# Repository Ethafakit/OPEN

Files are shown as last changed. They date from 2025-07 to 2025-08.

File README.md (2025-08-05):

# Ethafa Steammians Kit
Source files and activities of the Ethafa Steammians Kit released in open source.
**Ethafa Steammians** is an open-source educational toolkit designed to introduce children (ages 9–12) to STEAM and computational thinking through culturally grounded storytelling and hands-on experimentation.

This repository provides the complete resources needed to replicate, adapt, and expand the kit in educational settings.

---

## 🌍 About the Project

The kit was developed by [Ethafa](https://www.ethafa.com) to support playful and meaningful engagement with electronics, coding, and storytelling — particularly within Arabic-speaking and multicultural communities. It has been used in workshops across Switzerland, Gulf Countries and internationally.

---

## 📦 Repository Structure
- 3D_Case
- Activities
-    ├──Code_Wiring
-    ├──ENG
-    ├──ITA
- Eolim
-    ├──GRBL
-    ├──Graphics
-    ├──Schematics
- V-NO-PCB
-    ├──Eolim_Code_Cover_3D
-    ├──Resources for Educators

---

## 🛠 How to Use

1. **Build the kit**  
   Use the 3D files and PCB source files to manufacture the hardware. Moreover, you can use the "Version with no PCB" to run the activities with simple electronics components.

2. **Run the activities**  
   Open the `Activity` folder for guided activities using the Ethafa board.  
   For NoPCB version refer to the folder "Resources for Educators"

3. **Customize**  
   Educators and designers can use the Ethafa Framework to develop new culturally grounded activities. Please share your creation using the same licence.
   We’re always happy to support and learn about new initiatives inspired by Ethafa. Feel free to share them with us at info@ethafa.com.

---

## 🧩 Contributions

We welcome educators, designers, and developers to extend the kit. We’re always happy to support and learn about new initiatives inspired by Ethafa. Feel free to reach out and share them with us at info@ethafa.com.

---

## 📄 License

All content is openly licensed:
- Educational content: CC-BY 4.0
- Hardware and PCB: CERN-OHL-S v2
- Code: MIT License

---

## 🙌 Acknowledgements
This project was developed with support from:
- Gebert Rüf Stiftung: https://www.grstiftung.ch/de.html
- Venture Kick: https://www.venturekick.ch/
- Fablab SUPSI: https://www.supsi.ch/en/fablab
- Fondazione Leonardo: https://stiftungen.stiftungschweiz.ch/organisation/fondazione-leonardo
- VCUarts Qatar: https://qatar.vcu.edu/

Collaborations
- San3a Tech: https://www.san3atech.com/
- Fablab Bahrain: https://fablab.bh/
- Makerspace AlZaina: https://make.works/companies/make_uae
- Studio 5: https://www.studio5.qa/en/
- Swissnex: https://swissnex.org/
- Fondazione Agire: https://agire.ch/
- Ated4Kids: https://ated.ch/ated4kids
- CoderDojo: https://ated.ch/coderdojo
- Arduino: https://www.arduino.cc
- Roteco: https://www.roteco.ch/

List of talks, and community engament activities: https://trite-boot-688.notion.site/List-of-talks-interviews-and-workshops-2d0f7709cc704327aacfa6989071fbab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

---

## 📚 Citation

If you use this kit or adapt it for your own project, please cite us:

```bibtex
@misc{ethafa_steammians_2025,
  title={Ethafa Steammians Kit},
  author={Tawfik, Leyla and Cangiano, Serena},
  year={2025},
  doi={10.5281/zenodo.XXXXXXX},
  url={https://github.com/ethafa/steammians-kit}
}

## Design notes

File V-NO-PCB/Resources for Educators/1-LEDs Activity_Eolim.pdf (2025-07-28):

# Help Eulim inventing great things to help the Steammians

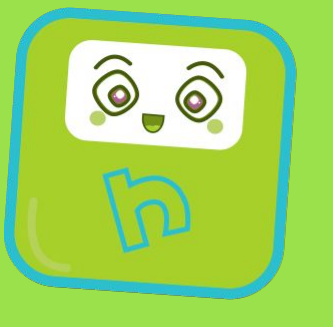
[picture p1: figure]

# live on planet earth!

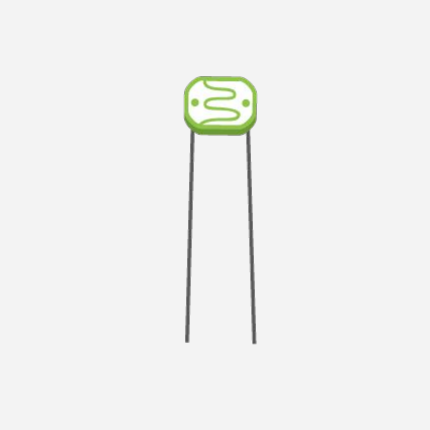
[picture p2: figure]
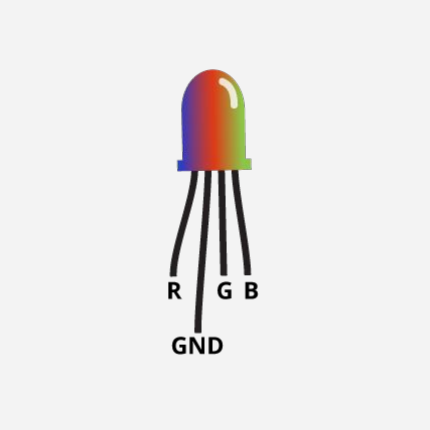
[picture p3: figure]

1x Photoresistor | 2x RGB LEDs

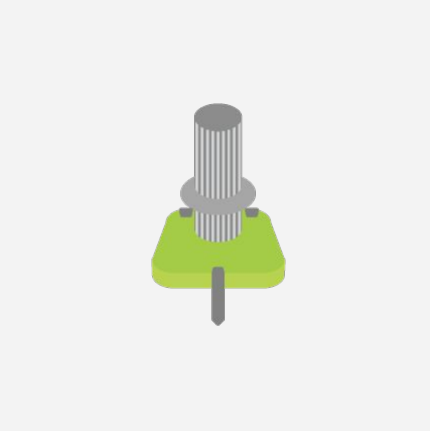
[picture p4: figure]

## 1x Potentiometer

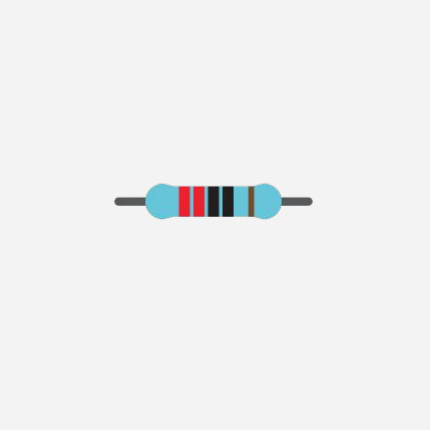
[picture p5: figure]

## 6x Resistor 220 ohm

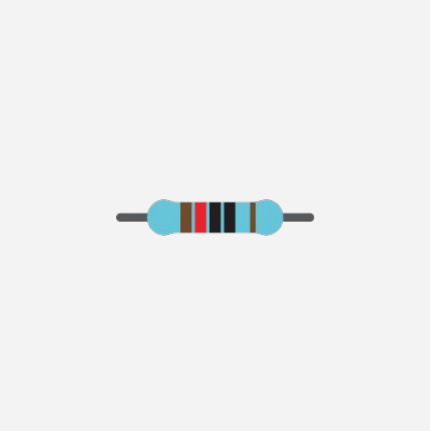
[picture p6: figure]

## 1x Resistor 10K ohm

# Here is all you need to build Eulim!

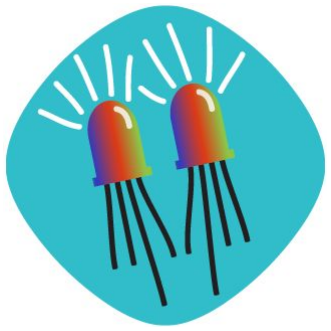
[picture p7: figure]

# Level 1 Special view

# STEP 1/4

Place the LEDs on the breadboard.

## NOTE: Remember where you place the longer lead!

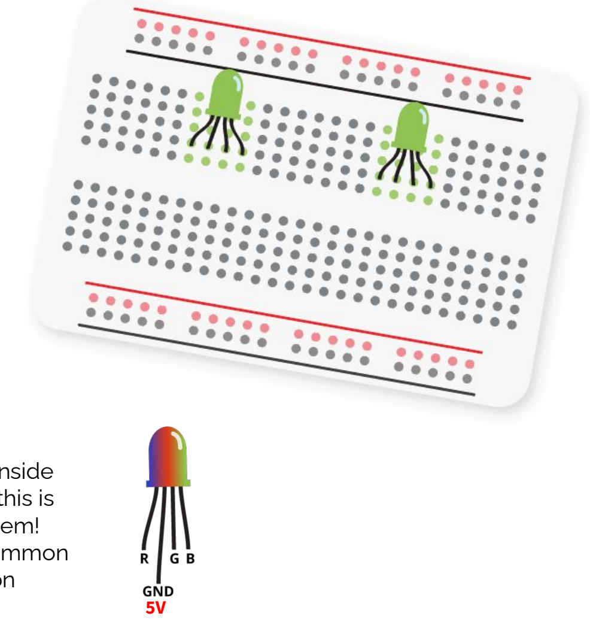
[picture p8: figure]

Electricity flows from the positive pole to the negative pole. Inside an RGB LED there 3 LEDs: one red, one green and une blue; this is why RGB LEDs can produce 3 different colors and a mix of them!
The RGB led has a longer lead than the other leads. In the common cathode case, it will be connected to GND and in the common
anode case; it will be connected to 5V. | 5V

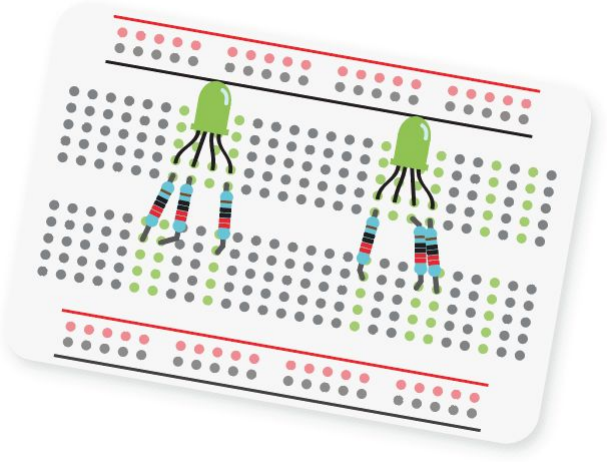
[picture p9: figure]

# STEP 2/4

## Now put the 220 ohm in correspondence of the shorter

leads.

Resistors allow changing the intensity of the electricity inside a circuit. If you don’t use them the eyes will explode!!! The intensity of electricity is measured in Ohm and you can recognize the different intensities by looking at the colored stripes.

LEARN MORE: HOW TO RESIST ELECTRICITY?

# STEP 3/4

## Connect the longer lead to the ground line on the breadboard

using two jumpers.

Jumper wires are used for making connections between items on your breadboard and your Arduino’s header pins. Use them to wire up all your circuits!

LEARN MORE: HOW TO MAKE CONNECTIONS?

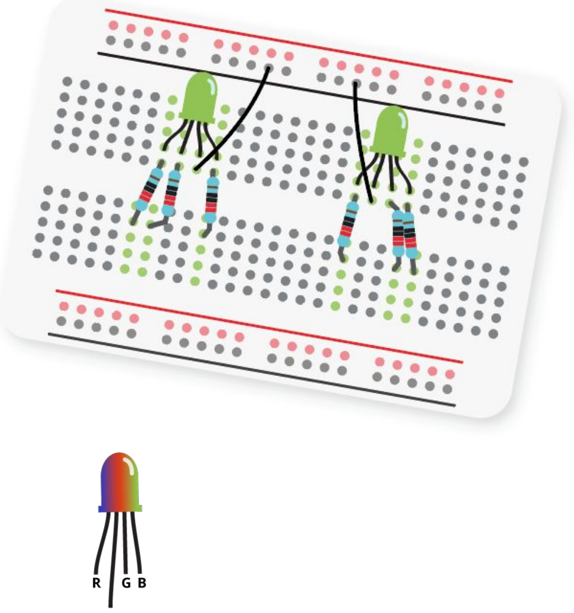
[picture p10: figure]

Remember what you read about the anode and cathode!!

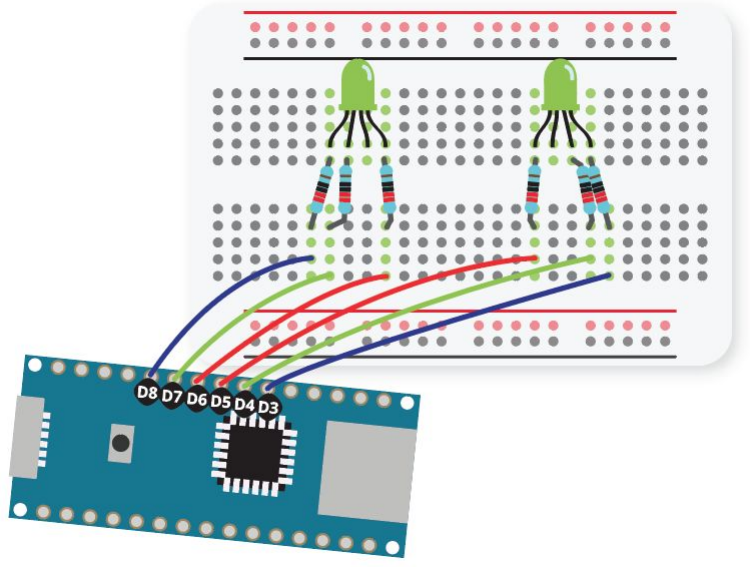
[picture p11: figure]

# STEP 4/4

## Lastly, connect the LEDs and resistor to the Arduino following the

instruction in the image.

The Arduino is a fundamental part of the circuit because it’s what tells the other components how to behave. It’s the brain of the Steammians! The Arduino is composed of different parts, one of them are the pins.

LEARN MORE: ARDUINO IS THE BRAIN!

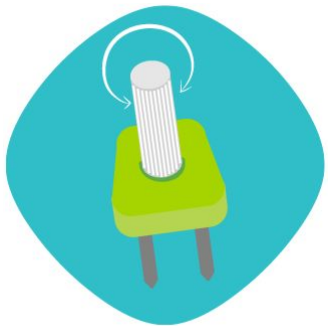
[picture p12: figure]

# Level 2 Idea boots

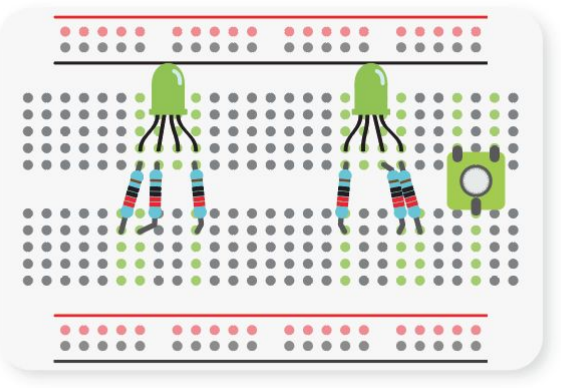
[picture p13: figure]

# STEP 1/3

## Place the potentiometer in the middle of the breadboard. Keep the

two leads at the top.

Potentiometer or pot is a variable resistor. The pot enables to change the blink rate or in this case, the color of the LED without changing any components in your circuit.

LEARN MORE: WHAT IS A POT?

# STEP 2/3

Connect the two terminals at the top. One to the ground and the other one to the positive line.

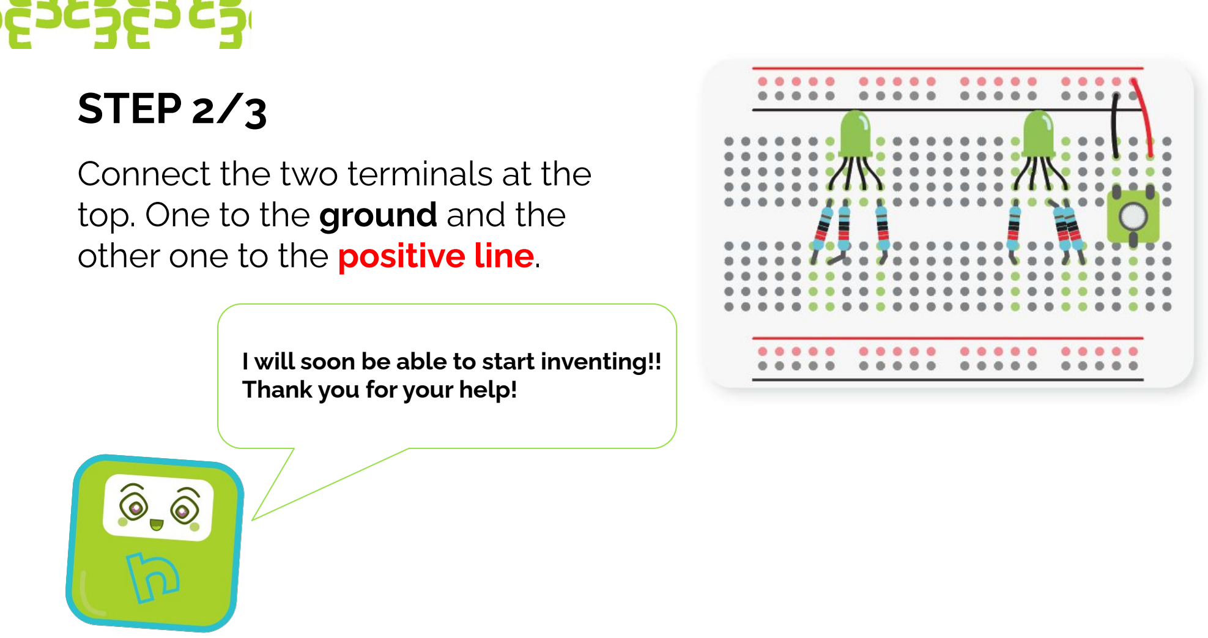
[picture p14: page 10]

I will soon be able to start inventing!! Thank you for your help!

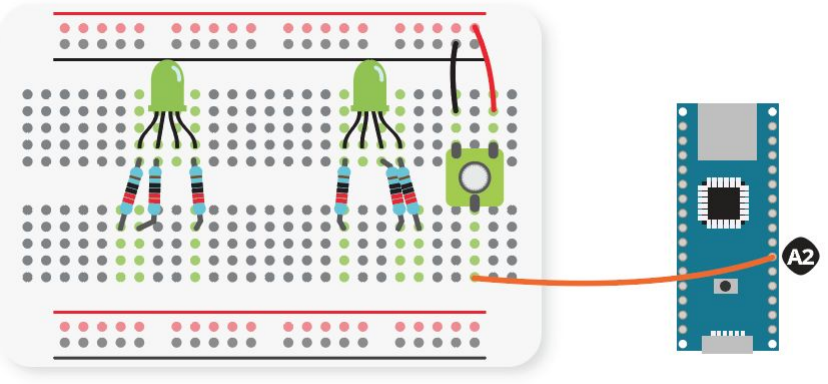
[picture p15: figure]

# STEP 3/3

## Lastly, connect the remaining

terminal to the pin A2 of the Arduino.

The Arduino has several different kinds of pins, each of which is labeled on the board and used for different functions. The “A” stands for analog. Those pins can read the signal from an analog sensor (like a temperature sensor) and convert it into a digital value from 0 to 1023 that we can read. The analog pin can measure physical phenomena around the Steammians.

LEARN MORE: WHAT IS THE “A” PIN?

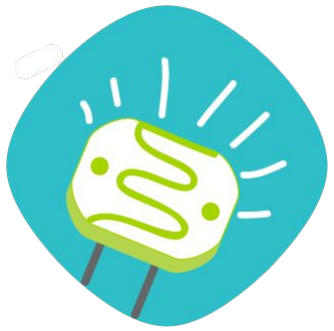
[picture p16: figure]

# Level 3 Light tracker

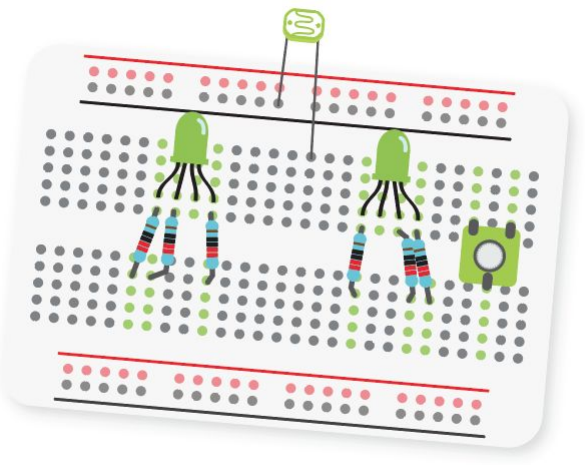
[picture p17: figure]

# STEP 1/3

## Place the photoresistor by insert one terminal in the ground line of the breadboard and the other one

in the neutral area.

The photoresistor read the amount of light in the ambient. It’s a conductor which resistance decreases with the increasing incident light intensity. This means that the more light hits the photoresistor, the more electricity it can conduct!

LEARN MORE: WHAT IS A PHOTORESISTOR?

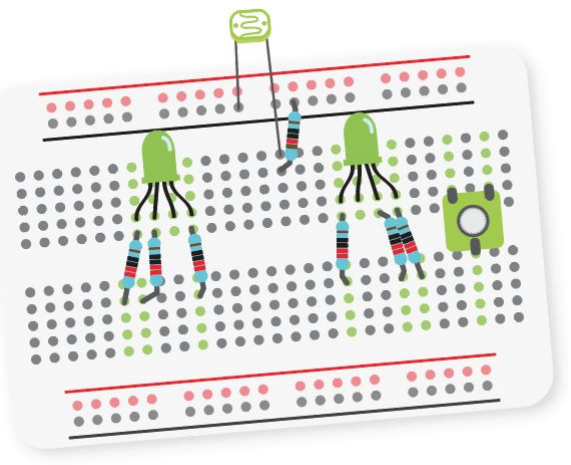
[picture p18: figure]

# STEP 2/3

## Now put the 10K resistance in correspondence of the terminal in

the neutral area of the breadboard.

The resistor’s resistance limits the flow of electrons through a circuit. The higher the value of the resistor the fewer electrons will pass through it. This means that if we want to pass more electricity through a circuit, we must use a resistor with a lower value.

LEARN MORE: WHAT THE 10K STANDS FOR?

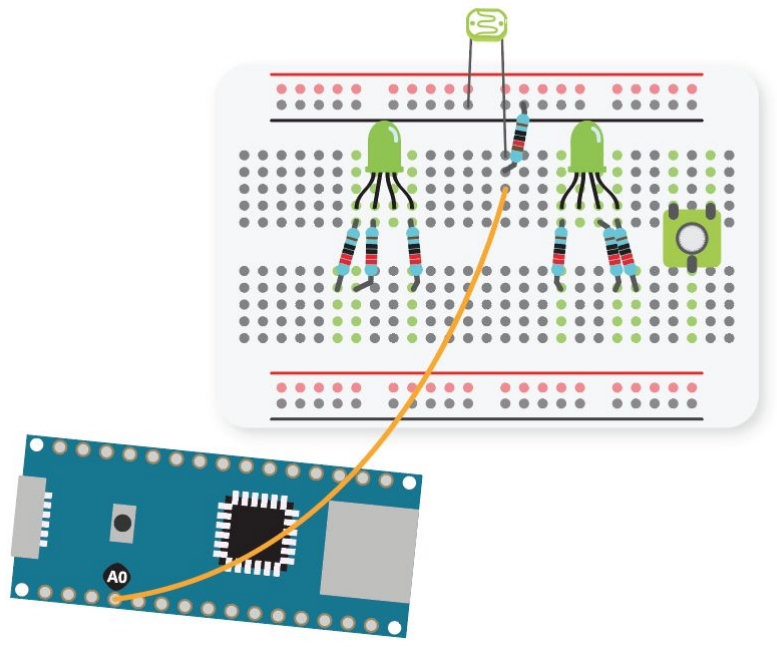
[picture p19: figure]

# STEP 3/3

## Connect the photoresistor terminal placed in the neutral area of the breadboard to the analog

pin A0 of the Arduino.

There are 13 digital pin in the Arduino (D1, D2...D13). These kind of pins can be used for both digital input (like telling if a button is pushed) and digital output (like powering an LED).

LEARN MORE: WHAT ARE THE DIGITAL PINS?

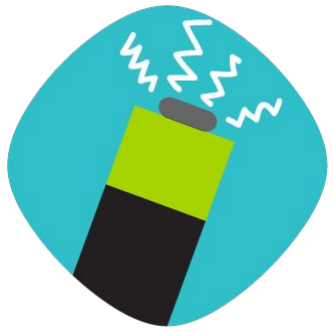
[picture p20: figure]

# Level 4 Level up energy

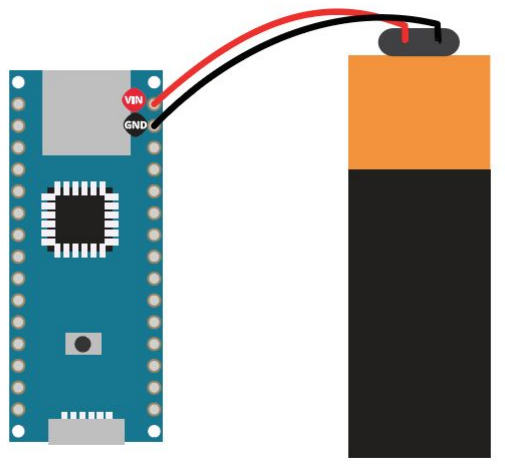
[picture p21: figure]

# STEP 1/2

## To make your circuit work you have to power it using a 9V battery! Connect the black wire to pin GND of the Arduino and the red one to the pin 5V!

The volt (symbol: V) is the unit that express the force that pushes electrons through a circuit to produce electricity. At the beginning of the circuit, electricity has a certain amount of force. It also has a certain amount of force at the end of the circuit. The difference between these two amounts is the voltage, measured in volts.

LEARN MORE: WHAT V STANDS FOR?

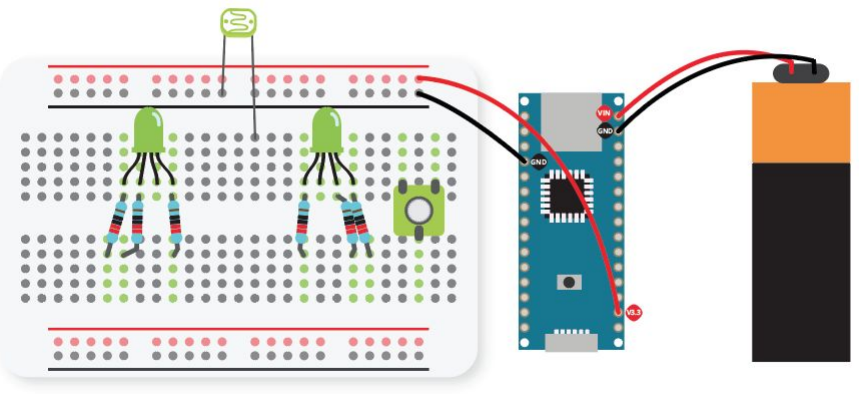
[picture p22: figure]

# STEP 2/2

## Finally, you need to power the breadboard! Connect the positive line to pin v3.3 and the ground line to

the remaining GND pin.

LEARN MORE: VIN vs. 3.3V
The Arduino as 4 pins that are related to power: 2 GND that are the same and have to be connected to the ground; then there are the 3.3 and VIN pins that have a positive polarity.
The difference among these two is that the VIN is the pin that power the Arduino (input) and can handle up to 20V, the 3.3V instead is an output and as suggested provide power up to 3.3V.

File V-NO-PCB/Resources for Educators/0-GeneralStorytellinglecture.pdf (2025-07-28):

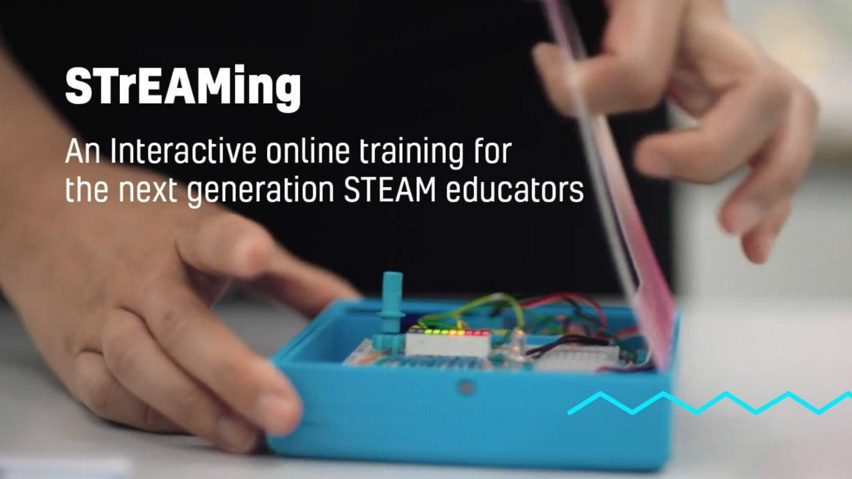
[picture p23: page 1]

© 2019 Ethafa

Part 2. Lecture 2.

# Storytelling in Tech education

© 2019 Ethafa

### Storytelling

Stories engage our thinking, emotions, and imagination all at once. As listeners we participate in the story with both mind and body as we enter the narrative world and react to it. Storytelling is a human art form that teaches about the human experience. As such, subjects even like math and science, are not

outside the world of human experience or the art of storytelling.

Storytelling in Teaching and Learning, NYU resources (https://www.nyu.edu/faculty/teaching-and-learning-resources/strategies-for-teaching-with-tech.html)

## The use of stories in STEAM why it is effective?

- students are proven to focus more when they follow a story, which logically has a
beginning | and | an | end.
- stories help to remember concepts in the long term
- stories allow to overcome intimidation or anxiety in learning new things.

## Playfulness

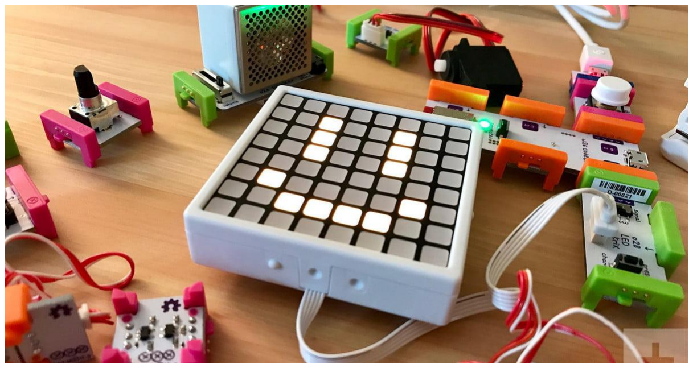
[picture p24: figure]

Playfulness

Storytelling is one of the tools used to design
playful | activities | for | children.

Play is one of the most important channels of psychological development, authentic trainer for future development.

Dot.

## Book and cartoon (0-5 years old)


Dot.

Dot is the story of “Dot’s a spunky little girl well versed in electronic devices—she’s a technophile. She knows how to tap, to swipe, to share and she pays little attention to anything else.”

The story tells the challenge of “unplug to tap, swipe, and share with her (Dot.) real-life friends”. The book wants to raise awareness around the “conscious” use of technology: computers are a resourceful tool in our everyday life, but it’s important to not detached this tool from real- world problems.

## Hello Ruby Book (5+ years old)


Hello Ruby

Hello Ruby started with a successful Kickstarter campaign, the book aims to teach the programming logic and culture. Nowadays there is no connection between humans and computers, people don’t know how computers works and the danger in this is that children grow to be “consumers of technology instead of creators”.

The protagonist of these stories is Ruby a six years old girl, interested in maps, secret codes, and small talk. Ruby is very curious about the world around her. The choice to have a girl as a protagonist is not casual, the book aims to start growing the next generation of smart girls

## Cubetto Stories


Cubetto stories

Cubetto is a “Screenless coding toy for girls and boys”. Cubetto is friendly robot that
teaches | children | basic | of | computer
programming | through | adventure | and
hands-on | | | | play.
Every adventure has a different goal and explore a different playgrounds “Ancient Egypt“, “Deep Space Adventure”, “Blue Ocean Adventure“ ect. Another possibility is to create your own setting and set in action new adventures using creativity and inexpensive materials.

## Thymio Stories


Thymio Stories

Thymio is a a modular affordable robot to let them discover digital technologies. The robot has six different behaviours. It reacts to hand-clapping, follow a black line on the floor, interact with other Thymio, be scared, explore or be obedient.
The different behaviours are used in during the activity by the kids in order to achieve a specific goal. “The island and the chest”
In this scenario kids have to guide Thymio to the treasure by using the buttons on top of the robot or the remote controller without touching the Kraken. All the elements of the story are paper elements.

## Design your educational story Workshop instructions

## The workshop aims to invent and document stories that can be used to teach a STEAM subject through an hands-on and playful activity

## What do you want to teach? What challenges do the students have to face? What is the story?

## Design your educational story Workshop canvas

### 1. STEAM content

What do you want to teach? list the STEAM contents you would like the kids to learn.

i.e. LED blinking, Growing plants

### 3. The story

Can you frame the challenge in a story? What is the story about? Could you include in the story the references to Bahrain’s history, culture and geography?

### 2. The challenge

What’s the challenge that kids should face? What’s the problem that you would like them to solve? Please describe it.

### 4. The activity

Please describe the activity. How long do the activity last? what do the students need to build? What are the materials? Should they have to present their project at the end? how? How do the students collaborate with each other?

## Design your educational story Workshop canvas

1. STEAM content | 2. The challenge | 3. The story

### 4. The activity

© 2019 Ethafa

## Thank you!

Follow our social channels!

@ethafakit

For more information visit our website: www.ethafa.com

Or contact us:
leyla@ethafa.com (Questions about Ethafa) serena@ethafa.com (Press and partnerships)

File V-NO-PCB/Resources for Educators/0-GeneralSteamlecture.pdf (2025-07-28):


© 2019 Ethafa

Part 1. Lecture 1.

## STEAM Education: best practices and general principles

### What is STEAM?


Teaching STEAM is not just about adding the subjects into the learning. To effectively teaching STEAM it’s important to incorporate hands-on learning; projects allow open-ended exploring and investigating, problems to solve and solutions to create. The more senses involved in education, the more it will help kids remember what they are learning. When kids are building, creating and exploring the learning matters to them. The experience that comes from hands-on projects makes learning more meaningful and engaging.

### What is STEM?


### What is STE(A)M?


STEAM takes STEM to the next level: it allows students to connect their learning in these critical areas together with arts practices, elements, design principles, and standards to provide the whole pallet of learning at their disposal. STEAM removes limitations and replaces them with wonder, critique, inquiry, and innovation.

www.educationcloset.com/what-is-steam-edu cation-in-k-12-schools/#whysteam

### What is STE(A)M?

STEAM programs aim to teach students to think critically and use engineering or technology in imaginative designs or creative approaches to real-world problems framed in social studies. STEAM programs add art to STEM curriculum by drawing on reasoning, ethics and design principles and encouraging creative solutions.


https://www.maind.supsi.ch/portfolio/2015-16/thesis/o-k ao (https://www.maind.supsi.ch/portfolio/2015-16/thesis/o-kao)

### Tech education


The fastest-growing job categories +9 millions job openings (just in USA)

### What is STEAM?


LOGO Turtle
Seymour Papert

The idea of programming is introduced through the metaphor of teaching the Turtle a new word. This is simply done, and children often begin their programming experience by programming the Turtle to respond to new commands invented by the child such as SQUARE or TRIANGLE or SQ or TRI or whatever the child wishes, by drawing the appropriate shapes.

S. Papert (1980), Mindstorms, Basic Books, New York, p.12

### What is STEAM?


Raytheon Lectron

The Lectron kit consisted of electronic components installed within individual "building blocks" with a clear plastic base, an opaque white top with the component's schematic symbol and permanent magnets attached to the leads of the enclosed components.

https://en.wikipedia.org/wiki/Raytheon_Lectron


### Some key principles


What STEAM brings into the classroom

1. Add More Hands-On Projects.
2. Include REAL World Problem Solving Activities.
3. Integrate and Apply the Learning.
4. Encourage Questioning and Wondering.
5. Give the Kids More Control of Their Learning.

www.teachbesideme.com

### Many online resources


Science buddies

A series of tutorials and resources to make hands-on science related activities

https://www.sciencebuddies.org/

### Many online resources


Code.org

A repository of resources to teach computer sciences in all grades.

www.code.org

### 21st Century Skills

Top 10 skills*

In 2015
1. Complex problem solving
2. Coordinating with others
3. People management
4. Critical thinking
5. Negotiation
6. Quality control
7. Service orientation
8. Decision making
9. Active listening
10. Creativity

*Future of jobs report, World Economic Forum

In 2020
1. Complex problem solving
2. Critical thinking
3. Creativity
4. People Management
5. Coordinating with others
6. Emotional intelligence
7. Decision making
8. Service orientation
9. Negotiation
10. Cognitive flexibility

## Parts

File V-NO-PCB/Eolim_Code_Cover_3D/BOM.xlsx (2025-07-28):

Eulim - BOM 1 | Number | Note
RGB LED | 2 | https://www.aliexpress.com/item/32809489418.html
Photoresistor | 1 | https://www.aliexpress.com/item/32976469984.html?s=p&ad_pvid=20200429120605647420179770000000903235_8
Potentiometer | 1 | https://www.aliexpress.com/item/32783054938.html
Resistor 220ohm | 6 | https://www.aliexpress.com/item/32810665767.html
Resistor 10K | 1
Jumpers | 4(small) / 10(long) | small: https://www.aliexpress.com/item/4000283658170.html
 |  | long: https://www.aliexpress.com/item/32850516506.html
Battery clip | 1 | https://www.aliexpress.com/item/4000579784240.html?ad_pvid=202004291200122230430834835220000892385_4&s=p
Breadboard | 1 | https://www.aliexpress.com/item/32803112223.html

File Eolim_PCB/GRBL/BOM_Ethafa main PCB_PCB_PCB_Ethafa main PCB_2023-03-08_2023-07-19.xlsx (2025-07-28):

No. | Quantity | Comment | Designator | Footprint | Value | Manufacturer Part | Manufacturer | Supplier Part | Supplier
1 | 2 | 1uF | C1,C2 | C0402 |  | GRM155R61C105KE01D | muRata(村田) | C77007 | LCSC
2 | 6 | 100nF | C3,C4,C5,C9,C12,C15 | C0402 |  | C1005X7R1C104KT000F | TDK | C338032 | LCSC
3 | 2 | 10nF | C6,C7 | C0402 |  | CL05B103KB5NNNC | SAMSUNG(三星) | C15195 | LCSC
4 | 2 | 10uF | C10,C13 | C0402 |  | CL05A106MP5NUNC | SAMSUNG(三星) | C315248 | LCSC
5 | 2 | 10pF | C11,C14 | C0603 |  | CL10C100JB8NNNC | SAMSUNG(三星) | C1634 | LCSC
6 | 2 | A2008WR-S-4P | CN_A7,CN_I2C | CONN-SMD_A2008WR-S-4P |  | A2008WR-S-4P | Changjiang Connectors | C273132 | LCSC
7 | 1 | 1N4148WS | D1 | SOD-323_L1.8-W1.3-LS2.5-RD |  | 1N4148WS | CJ(江苏长电/长晶) | C2128 | LCSC
8 | 1 | Ethafa 40pin header SMD - TOP | H1 | ETHAFA-40PINHEADER-BOTTOM-TOP |  | FH-00339 | Liansheng(连盛) | C2685112 | LCSC
9 | 1 | Ethafa 40pin header SMD - SX | H2 | ETHAFA-40PINHEADER-BOTTOM-SX |  | FH-00339 | Liansheng(连盛) | C2685112 | LCSC
10 | 1 | Ethafa 40pin header SMD - RX | H3 | ETHAFA-40PINHEADER-BOTTOM-RX |  | FH-00339 | Liansheng(连盛) | C2685112 | LCSC
11 | 2 | FH-00564 | H4,H5 | HDR-SMD_30P-P2.54-V-F-R2-C15-LS8.2-EH |  | FH-00564 | Liansheng(连盛) | C2685125 | LCSC
12 | 1 | 67-21S/KK5C-H572633Z6/2T(CLW) | LED1 | LED-SMD_L3.5-W2.8-RD |  | 67-21S/KK5C-H572633Z6/2T(CLW) | EVERLIGHT(亿光) | C385300 | LCSC
13 | 2 | MHS110FRGBCT | LED2,LED3 | LED-ARRAY-SMD_MHS110FRGBCT |  | MHS110FRGBCT | MEIHUA(美华) | C496820 | LCSC
14 | 2 | Ethafa Touch PAD | P_LEFT1,P_RIGHT1 | ETHAFA_TOUCH_PAD
15 | 1 | 2N7002KT1G | Q1 | SOT-23-3_L2.9-W1.3-P1.90-LS2.4-BR |  | 2N7002KT1G | onsemi(安森美) | C116584 | LCSC
16 | 3 | 2N7002NXAKR | Q2,Q3,Q4 | SOT-23-3_L2.9-W1.3-P1.90-LS2.4-BR |  | 2N7002NXAKR | Nexperia(安世) | C551416 | LCSC
17 | 2 | 22Ω | R1,R3 | R0402 |  | 0402WGF220JTCE | UNI-ROYAL(厚声) | C25092 | LCSC
18 | 5 | 100Ω | R2,R13,R14,R16,R17 | R0603 |  | 0603WAF1000T5E | UNI-ROYAL(厚声) | C22775 | LCSC
19 | 1 | 10kΩ | R4 | R0402 |  | 0402WGF1002TCE | UNI-ROYAL(厚声) | C25744 | LCSC
20 | 8 | 1kΩ | R5,R20,R21,R23,R24,R26,R28,R30 | R0402 |  | 0402WGF1001TCE | UNI-ROYAL(厚声) | C11702 | LCSC
21 | 5 | 100kΩ | R6,R10,R22,R25,R27 | R0402 |  | 0402WGF1003TCE | UNI-ROYAL(厚声) | C25741 | LCSC
22 | 1 | 0Ω | R7 | R0402 |  | 0402WGJ0000TCE | UNI-ROYAL(厚声) | C21376 | LCSC
23 | 3 | 160Ω | R8,R12,R15 | R0402 |  | 0402WGJ0161TCE | UNI-ROYAL(厚声) | C56581 | LCSC
24 | 1 | 4.7kΩ | R9 | R0402 |  | 0402WGF4701TCE | UNI-ROYAL(厚声) | C25900 | LCSC
25 | 3 | 1MΩ | R11,R18,R19 | R0402 |  | 0402WGF1004TCE | UNI-ROYAL(厚声) | C26083 | LCSC
26 | 1 | VEML6040A3OG | U1 | SENSOR_SMD_VEML6040A3OG |  | VEML6040A3OG | VISHAY(威世) | C78465 | LCSC
27 | 1 | MP23ABS1TR | U2 | RHLGA-5L_L3.5-W2.7-P0.82-MP23ABS1TR |  | MP23ABS1TR | ST(意法半导体) | C2827528 | LCSC
28 | 1 | MCP6002T-I/SN | U3 | SOIC-8_L4.9-W3.9-P1.27-LS6.0-BL |  | MCP6002T-I/SN | MICROCHIP(美国微芯) | C7377 | LCSC
29 | 1 | TYPE-C-31-G-07 | USB1 | USB-C-SMD_TYPE-C-31-G-07 |  | TYPE-C-31-G-07 | 韩国韩荣 | C530607 | LCSC
30 | 1 | 105450-0101 | USBC1 | USB-C-SMD_TYPE-C-USB-18 |  | 105450-0101 | MOLEX | C134092 | LCSC
31 | 2 | RH6015-C | U_P_LEFT1,U_P_RIGHT1 | SOT-23-6_L2.9-W1.6-P0.95-LS2.8-BR |  | RH6015C | RONGHE(融和) | C78180 | LCSC

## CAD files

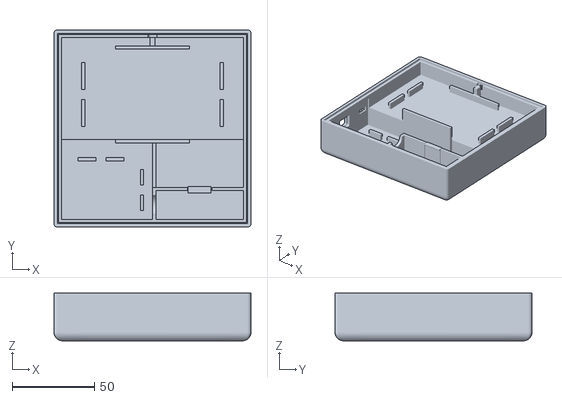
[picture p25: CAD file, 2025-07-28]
V-NO-PCB/Eolim_Code_Cover_3D/3D_Box_2017.stl
120.0 x 120.0 x 29.0

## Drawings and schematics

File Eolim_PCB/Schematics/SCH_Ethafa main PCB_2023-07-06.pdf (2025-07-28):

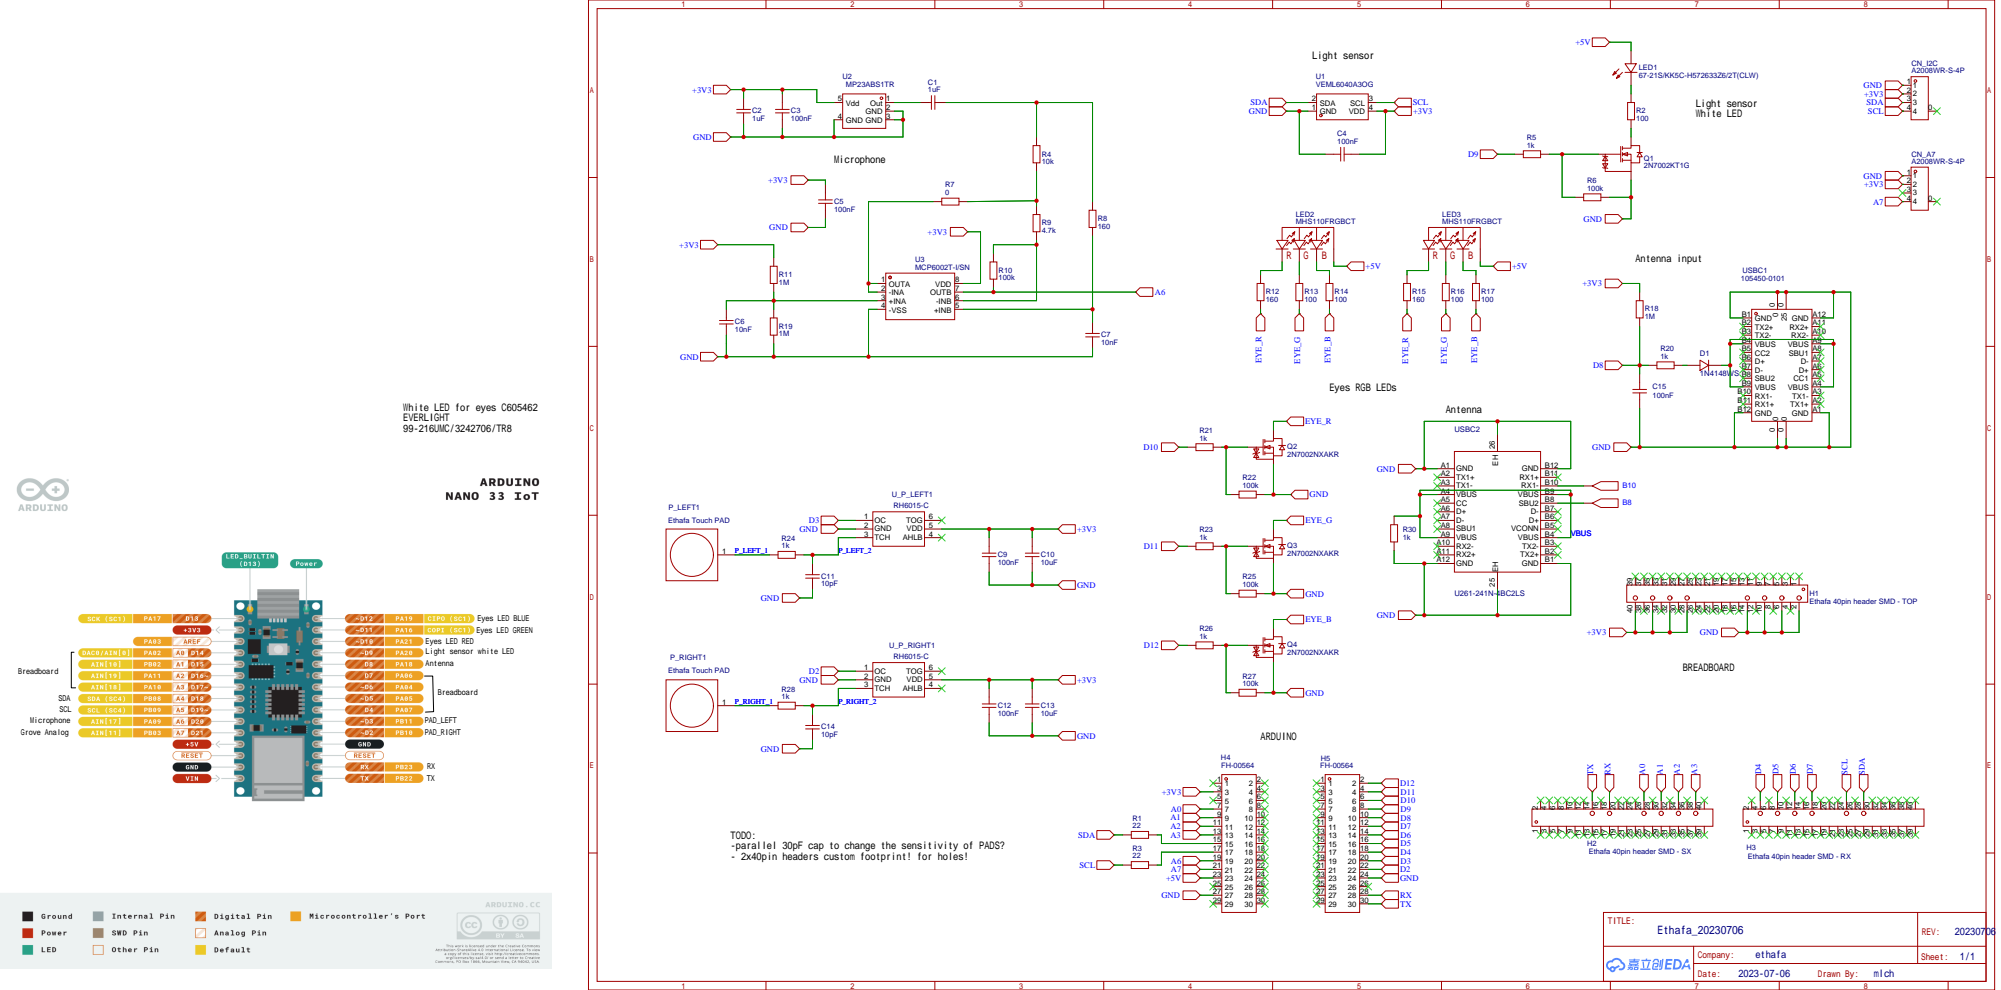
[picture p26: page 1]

Eyes LED RED
Light sensor white LED
Antenna

TODO:
-parallel 30pF cap to change the sensitivity of PADS?
- 2x40pin headers custom footprint! for holes!

Ethafa 40pin header SMD - SX

Ethafa 40pin header SMD - RX

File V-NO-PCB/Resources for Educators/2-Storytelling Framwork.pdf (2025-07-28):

## 1. STEM Content

# ETHAFA STEM FORMULA

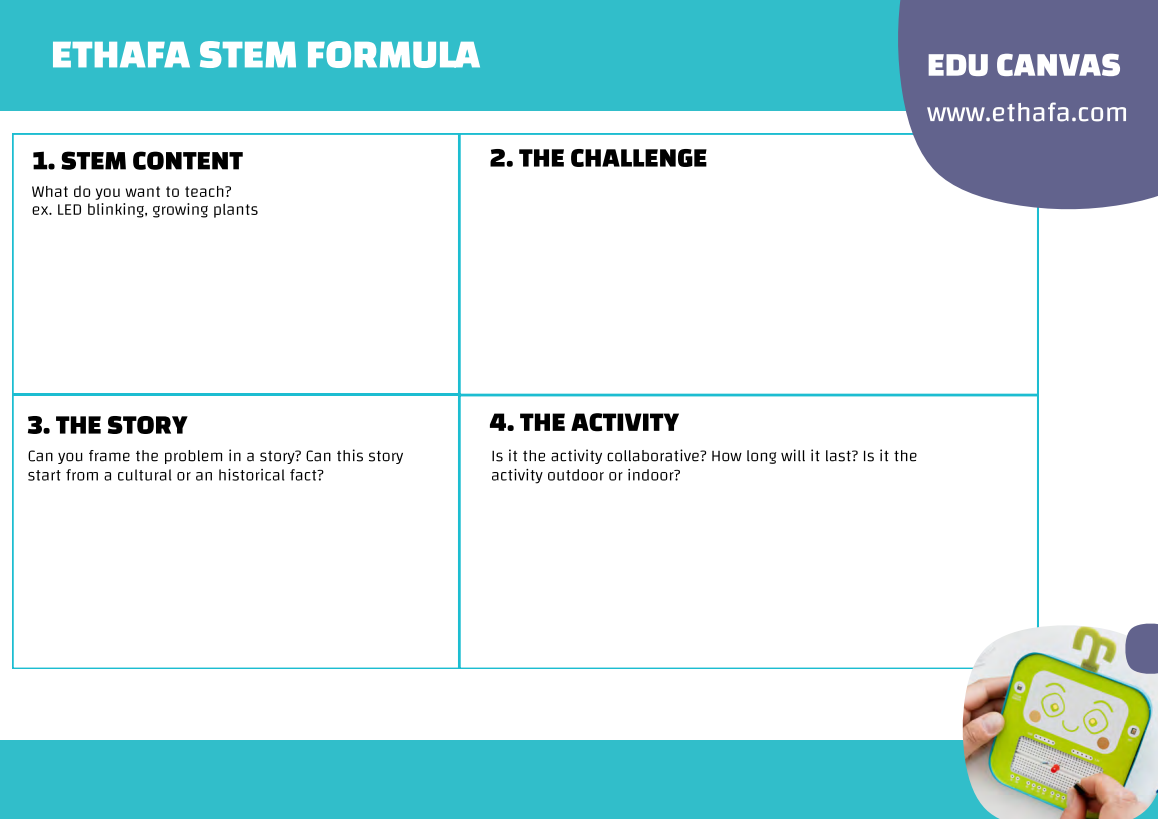
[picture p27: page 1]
2. THE CHALLENGE; 3. THE STORY; 4. THE ACTIVITY; EDU CANVAS

www.ethafa.com

What do you want to teach?
ex. LED blinking, growing plants

Can you frame the problem in a story? Can this story
start from a cultural or an historical fact?

Is it the activity collaborative? How long will it last? Is it the
activity outdoor or indoor?

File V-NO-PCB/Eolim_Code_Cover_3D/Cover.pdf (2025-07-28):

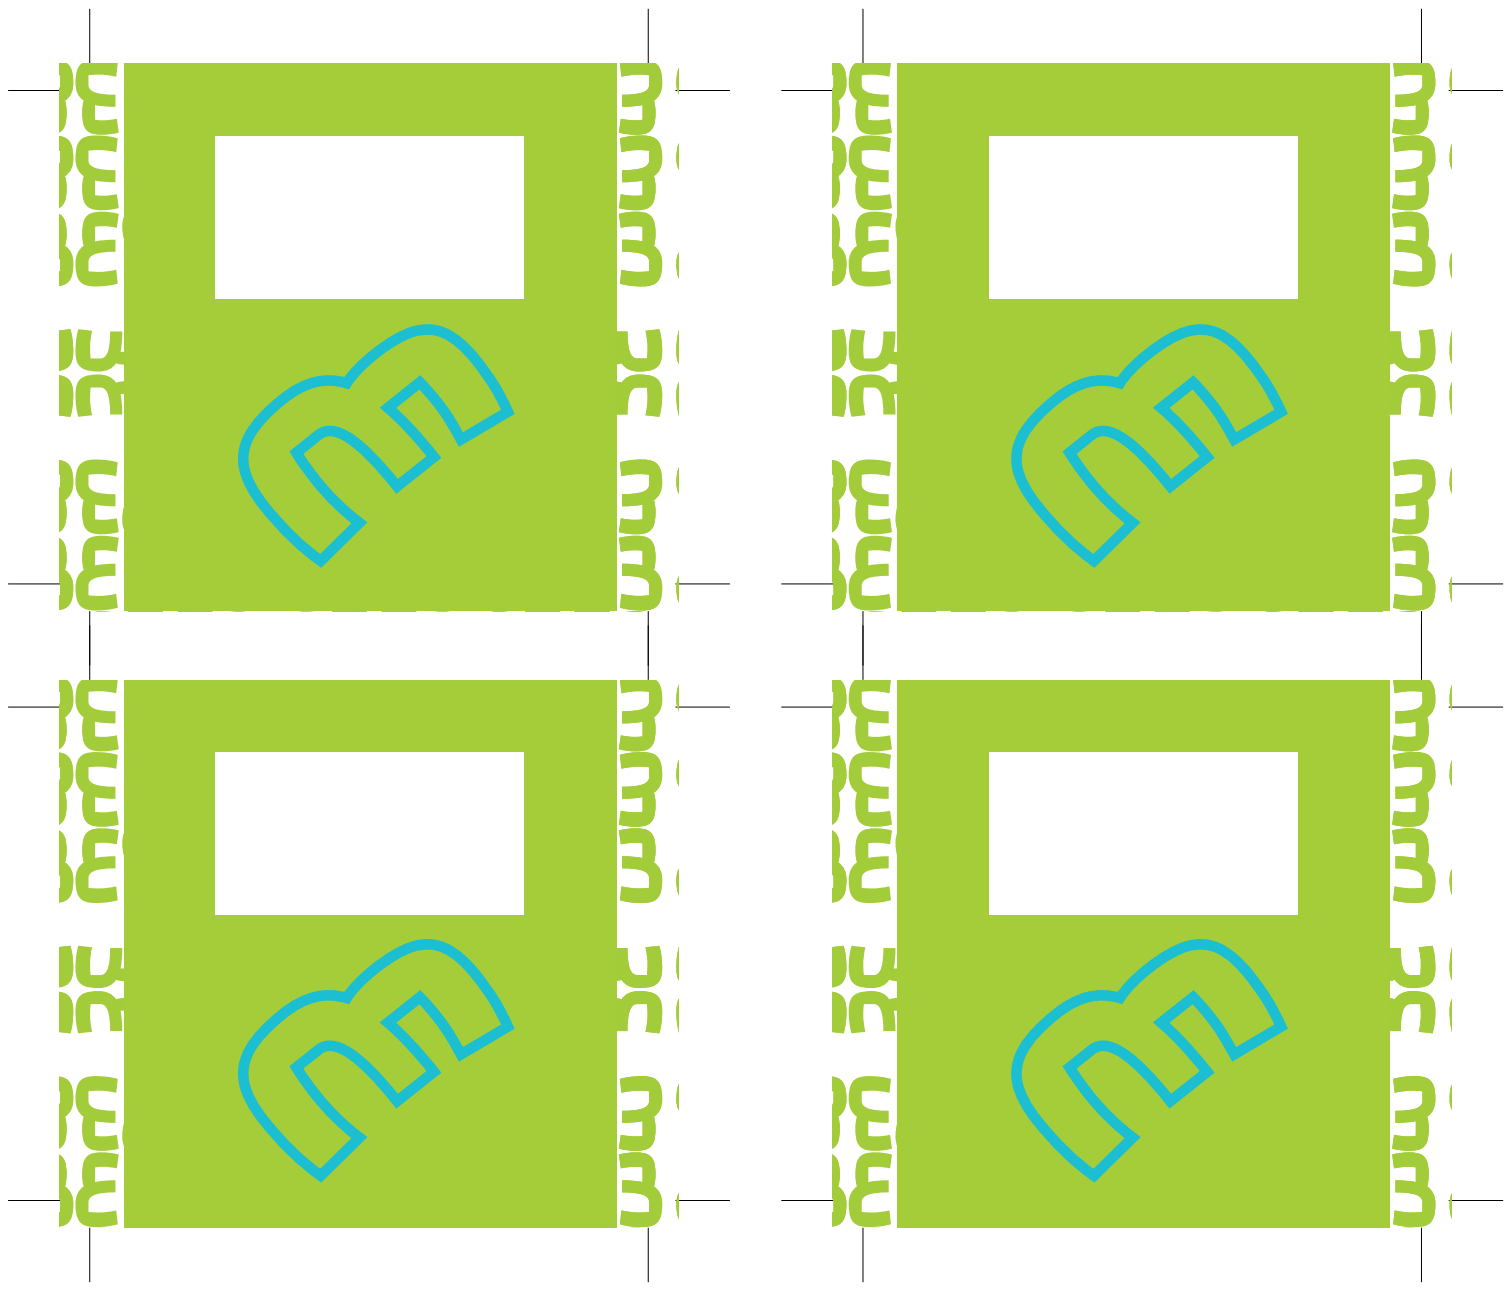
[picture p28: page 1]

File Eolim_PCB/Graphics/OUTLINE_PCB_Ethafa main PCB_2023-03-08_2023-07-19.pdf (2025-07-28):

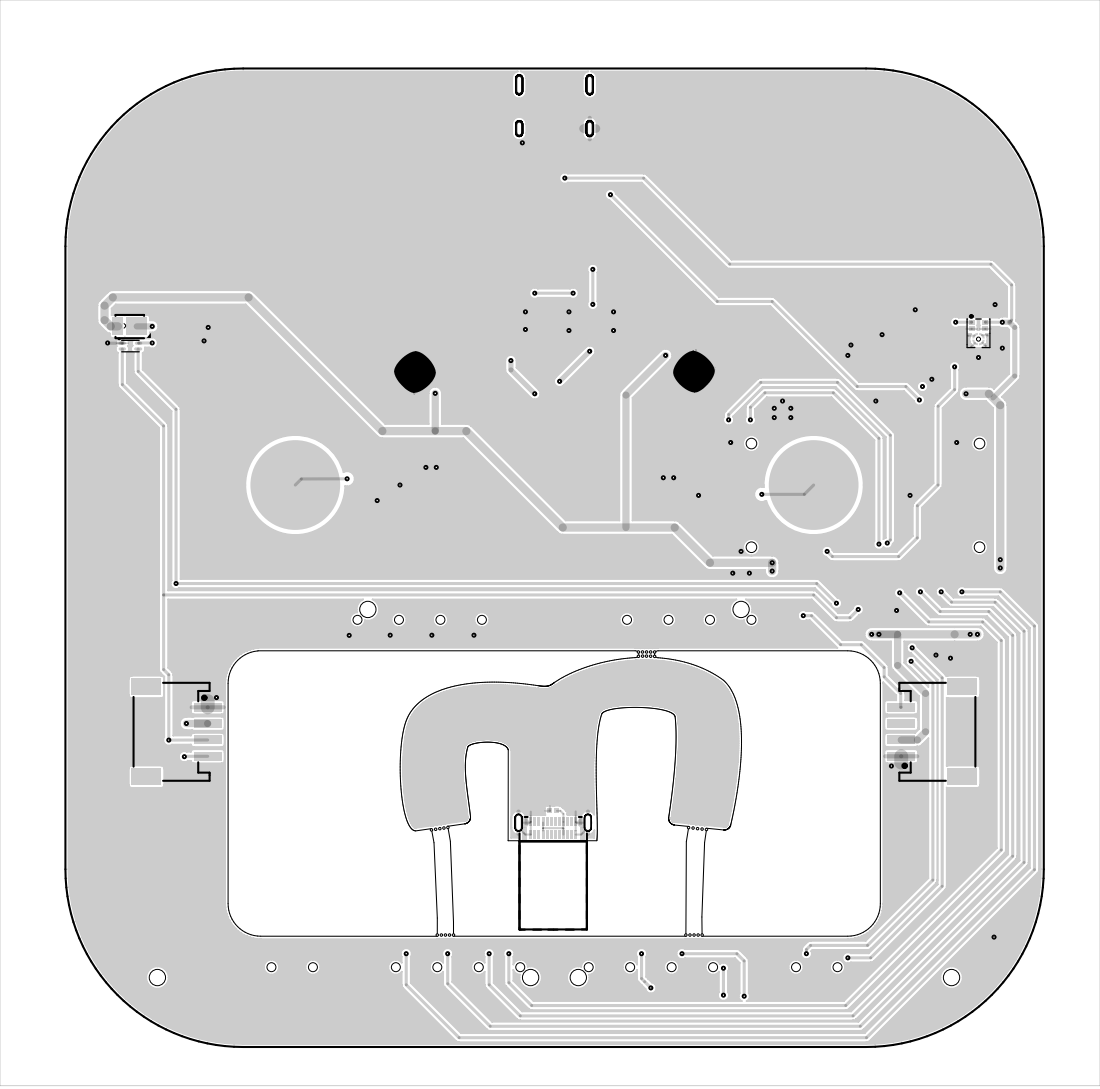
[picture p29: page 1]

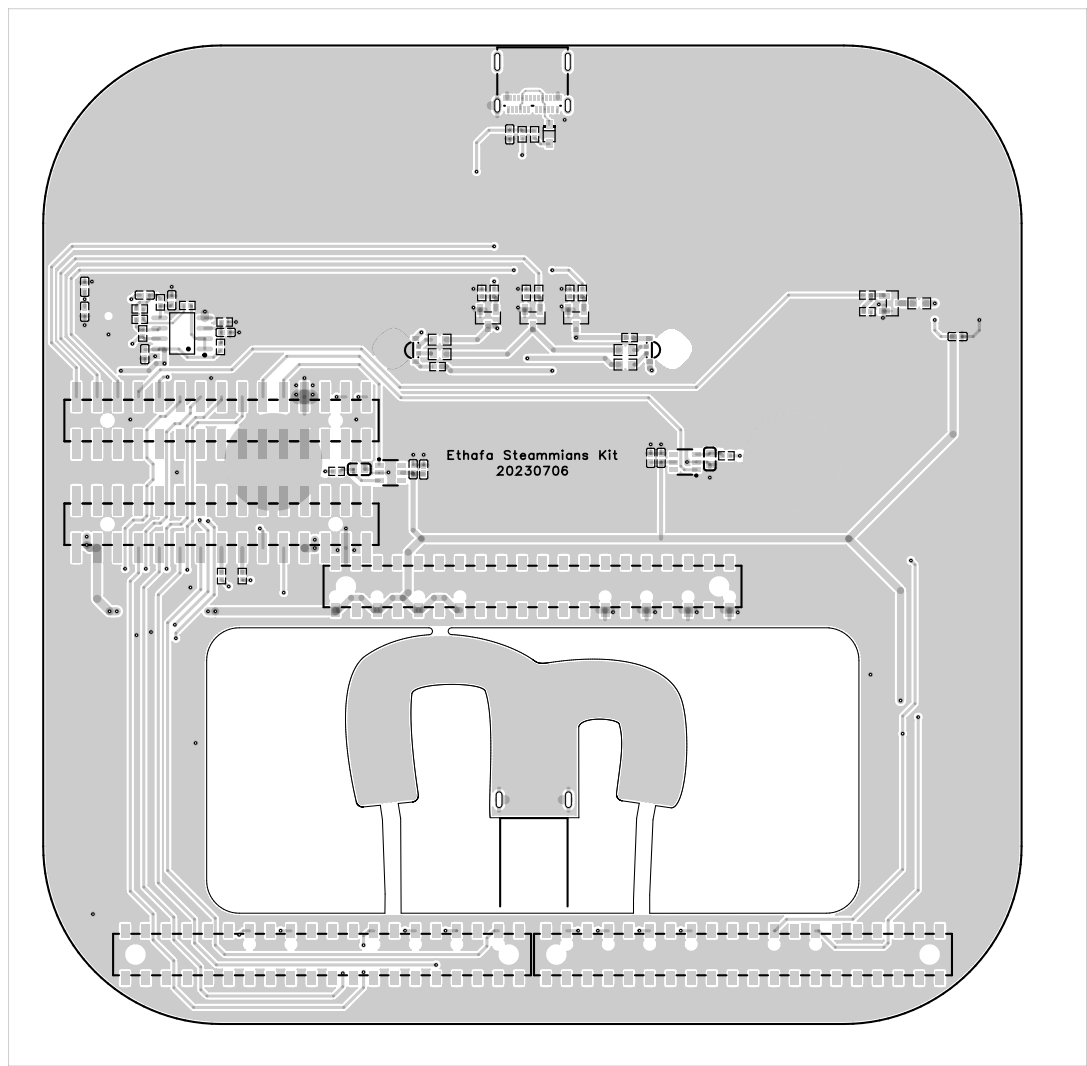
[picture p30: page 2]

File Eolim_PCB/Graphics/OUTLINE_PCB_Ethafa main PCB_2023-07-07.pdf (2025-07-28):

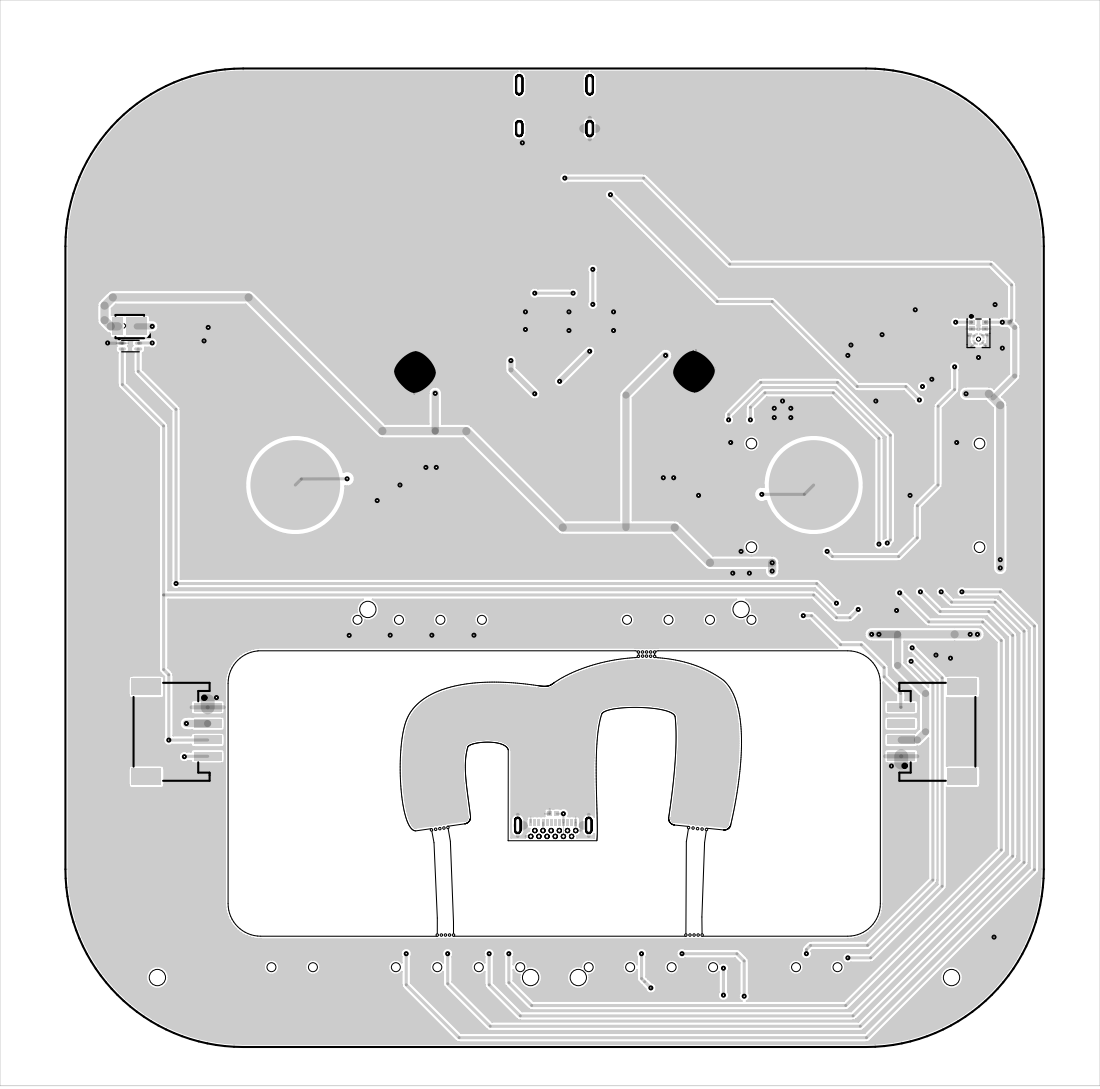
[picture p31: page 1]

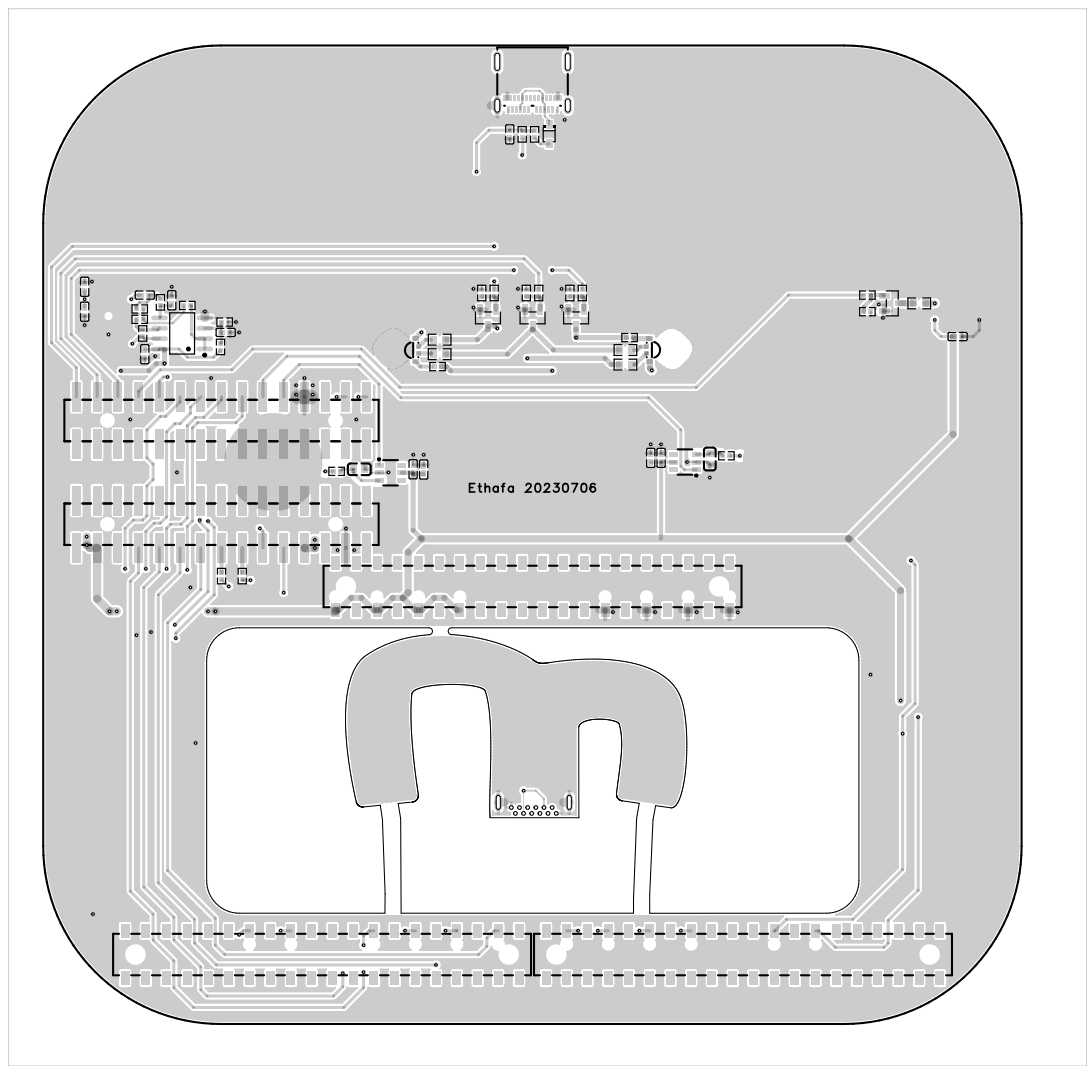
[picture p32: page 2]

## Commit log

2025-07-28 Create Eolim PCB
2025-07-28 Create Schematics
2025-07-28 Create GRBL
2025-07-28 Rename Activity 1_Code _ Wiring.zip to Activity 1_Code _ Wiring.zip
2025-07-28 Rename Activity 2_Code _ Wiring.zip to Activity 2_Code _ Wiring.zip
2025-07-28 Rename Activity 3_Code _ Wiring.zip to Activity 3_Code _ Wiring.zip
2025-07-28 Rename Activity 4_Code _ Wiring.zip to Activity 4_Code _ Wiring.zip
2025-07-28 Rename Activity 5_Code _ Wiring.zip to Activity 5_Code _ Wiring.zip
2025-07-28 Rename Activity 6_Code _ Wiring.zip to Activity 6_Code _ Wiring.zip
